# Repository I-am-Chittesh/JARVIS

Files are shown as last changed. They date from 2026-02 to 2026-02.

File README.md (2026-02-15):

# JARVIS

**Status:** Active Development (PCB Prototyping Phase)  
**Version:** v1.0.0-alpha

## 1. Overview
Project JARVIS is a dedicated, handheld hardware interface designed to bridge the physical world with the user’s digital ecosystem (**Physique.io** and **FlowState**). 

Unlike a smartphone, which is a source of distraction, JARVIS is a "Single-Purpose" tool designed to reduce friction. It allows the user to log data, authenticate work sessions, and capture visual context without ever unlocking a screen.

## 2. Core Functionality

### Voice Mode
* **Action:** Hold the dedicated voice button.
* **Function:** Captures high-fidelity audio commands (e.g., *"Logged 200g chicken breast"* or *"Add 'Fix API Bug' to Todo"*).
* **Backend:** Audio is synced via WiFi, processed by STT (Speech-to-Text), and parsed into the correct database (Notion/Physique.io).

### Pomodoro
* **Action:** Rotate the physical encoder to set a timer duration.
* **Function:** Initiates a "Deep Work" session. The device enters `FOCUS_MODE`, muting notifications and tracking the session in the FlowState database.

### Cam Module
* **Action:** Single-click to snap a photo; Long-press to record a 10s clip.
* **Function:** Uses a dedicated vision processor (ESP32-CAM) to capture workspace setups, meals, or project progress. Media is uploaded in the background.

### RFID Authentication
* **Action:** Tap an RFID card/tag.
* **Function:** * **Security:** Unlocks the device.
    * **Context Switching:** Triggers specific Spotify playlists (e.g., "Deep Focus" vs. "Gym Mode") via the Spotify API.

## 3. System Architecture
The device operates on a **Dual-MCU Architecture**:
* **Primary Brain:** ESP32-WROOM-32 (Handles WiFi, Audio, RFID, Logic).
* **Vision Brain:** ESP32-CAM (Handles Optics & SD Storage).

---
*Built with ❤️ by I_am_Chittesh*

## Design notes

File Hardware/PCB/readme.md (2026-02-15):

# PCB

This design was made using **KICAD**.

### Please download the entire file directory of the PCB files before editing to avioid unecessary consequences.

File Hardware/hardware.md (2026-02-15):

# JARVIS Hardware Specification (Rev 1.0)

**Architecture:** Modular Carrier Board (Motherboard Style)  
**PCB Type:** Single-Sided FR4  
**Power System:** 5V Boosted LiPo (USB-C Rechargeable)

## Design
To ensure repairability and ease of assembly, the JARVIS Mainboard does not use surface-mount (SMD) chips for complex logic. Instead, it acts as a **Carrier Board** with Female Header Sockets. 
* **Modules (ESP32, Charging, Boost):** Plugged into headers (Replaceable).
* **Interface (USB, Buttons, LEDs):** Soldered directly (Through-Hole).

## Hardware Pinout Strategy

### Power Flow
`USB-C (5V)` -> `TP4056` -> `Battery (3.7V)` -> `Switch` -> `MT3608 Boost` -> `5V SYSTEM RAIL`

### User Interface Logic
The device uses dedicated buttons to switch the system `State Machine`.

| Hardware Input | Designated Function | Indicator LED |
| :--- | :--- | :--- |
| **Button 1** | **POMODORO MODE** (Timer Set/Start) | 🔴 Red LED |
| **Button 2** | **CAMERA MODE** (Wake ESP32-CAM) | 🟢 Green LED |
| **Button 3** | **RFID MODE** (Scan Tag/Unlock) | 🔵 Blue LED |
| **Rotary Encoder** | **SCROLL / SELECT** (Global) | N/A |

## Assembly Notes (Warning)
1.  **Voltage Calibration:** You **MUST** plug in the MT3608 Boost Module alone first, and turn the potentiometer screw until the output reads **5.0V**. If it reads 9V or 12V, it will destroy the ESP32s.
2.  **Socket Orientation:** Ensure the Female Headers for the ESP32-CAM are soldered correctly; the module has no reverse-voltage protection.

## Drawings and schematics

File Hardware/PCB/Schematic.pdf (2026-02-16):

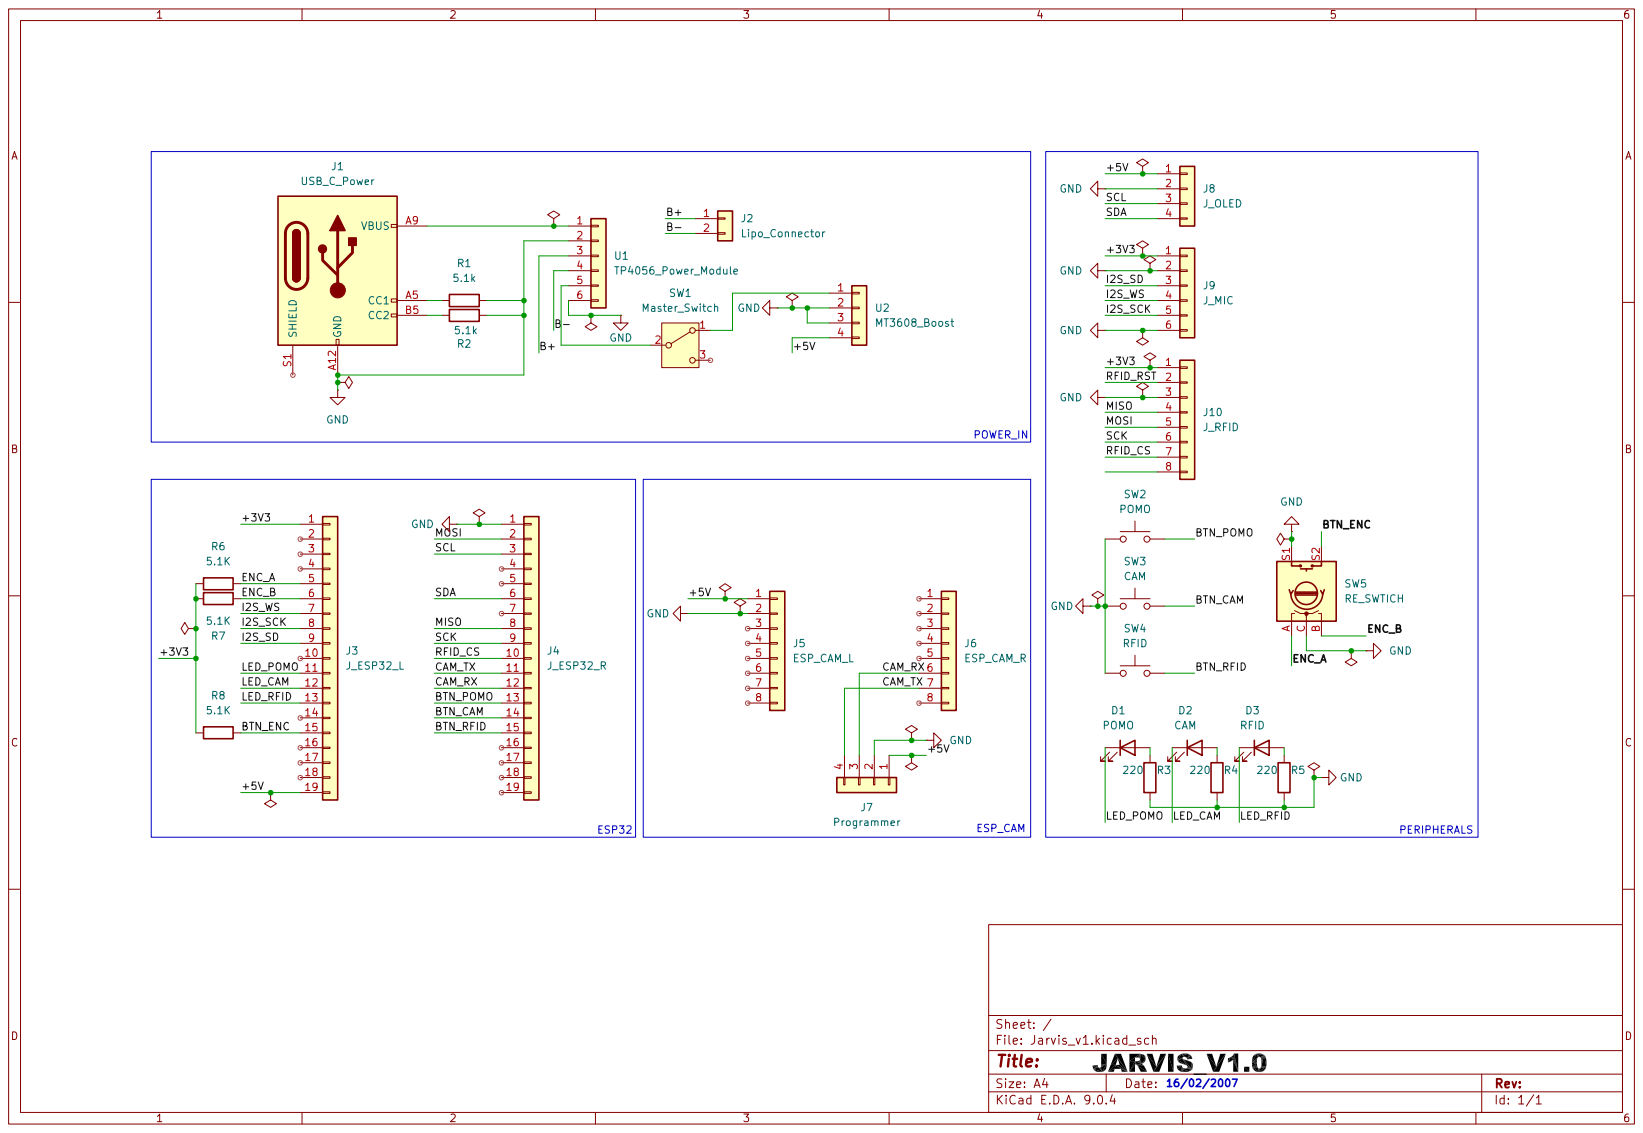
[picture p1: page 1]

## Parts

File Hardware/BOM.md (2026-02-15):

## BOM

### A. The Brains (Plug-in Modules)
| Component | Quantity | Footprint | Notes |
| :--- | :--- | :--- | :--- |
| **ESP32-WROOM-32 DevKit V1** | 1 | 2x15 Pin Headers | Primary Logic Unit. (Ensure 30-pin version). |
| **ESP32-CAM (AI Thinker)** | 1 | 1x16 Pin Header | Dedicated Vision Unit. |

### B. Power System (Hybrid THT/Module)
| Component | Quantity | Footprint | Notes |
| :--- | :--- | :--- | :--- |
| **USB-C Connector (6-Pin)** | 1 | THT (Type-C) | **Native PCB Component.** (Pins: VBUS, GND, CC1, CC2). |
| **TP4056 Charging Module** | 1 | Header Socket | Lithium Battery Charger (5V Input). |
| **MT3608 Step-Up Module** | 1 | Header Socket | **Crucial:** Must be calibrated to 5.0V output before use. |
| **LiPo Battery** | 1 | JST-PH 2.0 | 3.7V, 2000mAh (Flat Pack). |
| **Slide Switch (SPDT)** | 1 | THT (SS-12D00) | Master System ON/OFF (Cuts Battery Line). |
| **Resistor (5.1kΩ)** | 2 | THT (1/4W) | Pull-down resistors for USB-C CC lines (Required for C-to-C charging). |

### C. Sensors & Input
| Component | Quantity | Footprint | Notes |
| :--- | :--- | :--- | :--- |
| **INMP441 Microphone** | 1 | Header Socket | I2S Digital Audio Interface. |
| **RC522 RFID Reader** | 1 | Header Socket | SPI Interface (13.56MHz). |
| **Rotary Encoder (EC11)** | 1 | THT (5-pin) | Includes Push Button (Menu Select). |
| **Tactile Buttons** | 3 | THT (6x6mm) | Mode Selectors (Pomo, Cam, RFID). |

### D. Output & Indicators
| Component | Quantity | Footprint | Notes |
| :--- | :--- | :--- | :--- |
| **1.3" OLED Display** | 1 | Header Socket | I2C Interface (SSD1306 Driver). |
| **LED (3mm/5mm)** | 3 | THT | Status Indicators: Red (Focus), Green (Cam), Blue (Auth). |
| **Resistor (220Ω)** | 3 | THT (1/4W) | Current limiting for Status LEDs. |
